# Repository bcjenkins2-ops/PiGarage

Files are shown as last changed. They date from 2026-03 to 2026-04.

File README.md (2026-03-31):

# PiGarage

Open-source Raspberry Pi power management and audio HAT for automotive head-unit use.

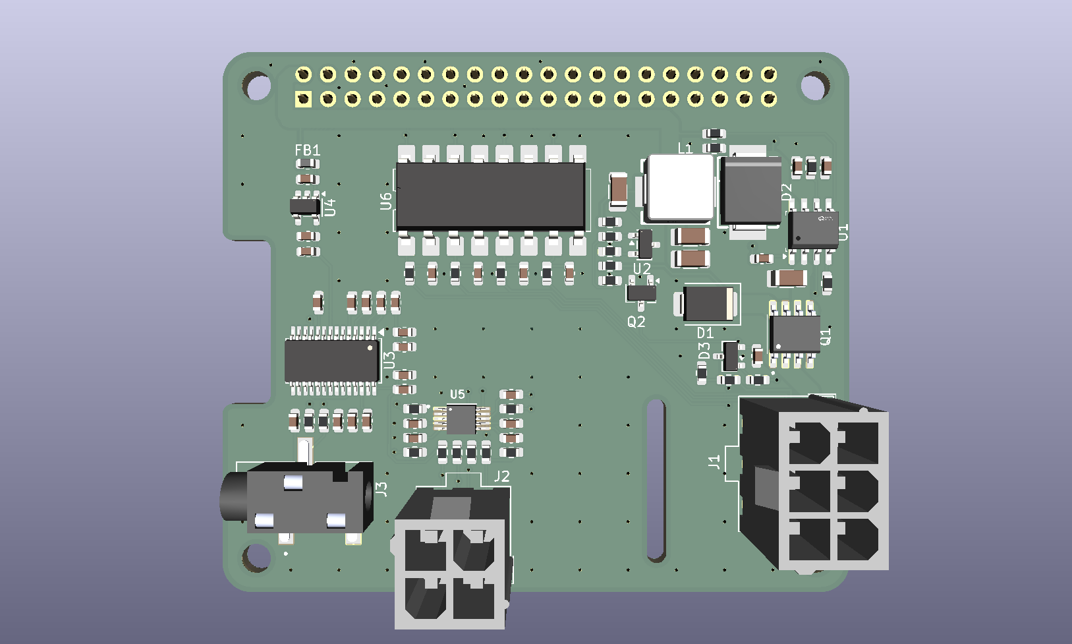
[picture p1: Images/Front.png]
PiGarage Board


## Features

- **5V 5A Buck Converter** (TPS54560BQDDARQ1) — 7-16V input, Pi 5 compatible
- **I2S DAC** (PCM5122PWR) — 112dB SNR, noise-free audio output to external amplifier
- **ADC** (ADS1115) — 16-bit, for steering wheel resistor ladder controls
- **4-Channel Optoisolated 12V Sensing** — ACC, REV, ILL, AUX via LTV-847S
- **Safe Shutdown** — ACC-triggered power latch with GPIO hold (BCM25), crank ride-through
- **Battery Protection** — UVLO hard cutoff at 12.08V via TL431A comparator
- **Compatible** — Raspberry Pi 3, 4, and 5

## Board

| Parameter | Value |
|---|---|
| Input Voltage | 7-16V (automotive 12V) |
| Output Voltage | 5.0V |
| Output Current | 5A continuous |
| DAC SNR | 112dB |
| DAC Interface | I2S |
| ADC Resolution | 16-bit, 4-channel |
| Sense Inputs | 4ch optoisolated |
| Board Format | Raspberry Pi HAT (65mm x 56.5mm) |

## Directory Layout

```
PiGarage/
├── Hardware/           KiCad 10 schematic, PCB, and custom libraries
├── Production/         Gerbers, drill files, pick-and-place
├── BOM/                Bill of Materials and design notes
├── Images/             Board renders and schematic exports
├── Software/           Power latch daemon and systemd service
└── Docs/               Ordering and assembly guide
```

## Getting Started

See [Docs/ordering-guide.md](Docs/ordering-guide.md) for full instructions on ordering from JLCPCB and assembling the board.

## License

Hardware: [CERN-OHL-S-2.0](https://ohwr.org/cern_ohl_s_v2.txt) — Software: MIT

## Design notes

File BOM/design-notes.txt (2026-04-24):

# PiGarage — Bill of Materials (BOM) Reference
**Last updated: 2026-04-25 (rev 15 — 0402→0603 passives for JLCPCB assembly)**

All SMT parts assembled by JLCPCB PCBA unless noted.

**Hand-solder (4 through-hole parts):**
- 40-pin GPIO header 2×20
- Molex Mini-Fit Jr 6-pin car harness header
- Molex Mini-Fit Jr 4-pin ADC header
- PJ-320B 3.5mm TRS audio jack

**Wire-side parts (DigiKey — see Section 7 for full shopping list):**
- Discrete cable assemblies: cut in half for colour-coded pigtails

---

## SECTION 1 — POWER INPUT & PROTECTION

**7.5A ATO/ATC fuse is installed in the car harness before J1, not on the PCB. Document only — no schematic symbol.**

### 2. SMBJ18CA/TR13 — TVS Diode
- **JLCPCB:** C78413
- **Package:** SMB (DO-214AA)
- **Mfr:** Brightking
- **Rating:** 600W, 18V standoff, BIDIRECTIONAL
- **Stock:** ~62,000
- **Notes:** BIDIRECTIONAL essential 

### 2b. B560C-13-F — Catch (Freewheeling) Schottky Diode
- **JLCPCB:** C85100
- **Package:** SMC (DO-214AB)
- **Mfr:** Diodes Incorporated
- **Specs:** 60V, 5A, Vf 0.7V typ @ 5A, -55 to +125°C
- **Notes:** REQUIRED — TPS54560B is asynchronous (high-side MOSFET only). External catch diode provides freewheeling path for inductor current when high-side FET turns off. Without this diode the converter will not function. Connect anode to GND, cathode to SW pin. Place as close to buck IC as possible with short, wide traces. SMC package chosen over SMA for better thermal performance at sustained 5A (θJA ~45°C/W vs ~90°C/W). Diode dominates thermal budget (~2W at full load) — ensure adequate copper pour under thermal pad.

---

## SECTION 2 — BUCK CONVERTER (12V → 5V @ 5A)

**Compensation designed with TI WEBENCH (7-16V in, 5V/5A out, ~1.1MHz fsw):**
```
Rcomp = 23.7kΩ, Ccomp = 1.8nF, Ccomp2 = 8.2pF
Rfbt = 60.4kΩ, Rfbb = 11.5kΩ → Vout = 0.8 × (1 + 60.4k/11.5k) = 5.0V
Rt = 80.6kΩ → fsw ≈ 1.1MHz
L1 = 2.2µH (molded/shielded)
```

### 3. TPS54560BQDDARQ1 — Buck Converter IC
- **JLCPCB:** C2072188
- **Package:** SOP-8-EP
- **Mfr:** Texas Instruments
- **Specs:** 4.5-60V in, 5A out, AEC-Q100, 500kHz
- **Stock:** ~1,271

### 4. cjiang FXL0630-2R2-M — Inductor 2.2µH
- **JLCPCB:** C167218 (Extended)
- **Package:** SMD 7×6.6mm molded (shielded)
- **Specs:** 2.2µH, Isat 10A, Irms 9.5A, DCR 15mΩ, ±20%
- **Notes:** WEBENCH recommended 2.2µH for 7-16V input at ~1.1MHz fsw. Molded construction reduces EMI — important with DAC on same board. 10A Isat exceeds TPS54560B 7.5A peak current limit with margin. 15mΩ DCR gives 0.375W loss at 5A (better than previous 26.5mΩ).

### 5. Samsung CL31A476MPHNNNE — 47µF Ceramic Output Capacitor (×2)
- **JLCPCB:** C96123 (Basic)
- **Package:** 1206
- **Specs:** 47µF, 10V, X5R, ±20%
- **Stock:** ~497,515
- **Qty:** 2 (in parallel on VOUT rail)
- **Notes:** WEBENCH design at 1.1MHz requires ≥22.7µF effective output capacitance (load transient). 2× 47µF at 10V gives ~70-76µF effective after DC bias derating at 5V. 10V rating chosen per TI reference design for good capacitance retention at 5V output.

### 6. Capacitor — 1µF X5R 0603 (HF bypass parallel with item 5)
- **JLCPCB:** C15849 (Basic)
- **Mfr:** Samsung CL10A105KB8NNNC
- **Specs:** 1µF, 50V, X5R, 0603

### 7. Resistor — 60.4kΩ (Rfbt, feedback divider top)
- **JLCPCB:** C23089 (Extended)
- **Specs:** 60.4kΩ, 1%, 0603
- **Notes:** Vout = 0.8 × (1 + 60.4k/11.5k) = 5.0V. WEBENCH value.

### 8. Resistor — 11.5kΩ (Rfbb, feedback divider bottom)
- **JLCPCB:** C2930057 (Extended)
- **Specs:** 11.5kΩ, 1%, 0603

### 9. Resistor — 80.6kΩ (RT, switching frequency)
- **JLCPCB:** C23249 (Extended)
- **Specs:** 80.6kΩ, 1%, 0603
- **Notes:** RT/CLK pin to GND → fsw ≈ 1.1MHz. WEBENCH value for 7-16V input.

### 10. Capacitor — 100nF X7R 0603 (BOOT pin)
- **JLCPCB:** C14663 (Basic)
- **Mfr:** YAGEO CC0603KRX7R9BB104
- **Specs:** 100nF, 50V, X7R, 0603
- **Notes:** BOOT cap sits between BOOT and SW pins per datasheet. Voltage across cap = ~5.4V (bootstrap charge), NOT 19.8V to GND. 50V rating provides 9.3× derating. All 100nF caps on the board now use C14663 (0603).

### 10b. Capacitor — 4.7µF 50V X7R 1206 (VIN input capacitor)
- **JLCPCB:** C29823 (Basic)
- **Mfr:** FH (Guangdong Fenghua) 1206B475K500NT
- **Specs:** 4.7µF, 50V, X7R, 1206
- **Stock:** ~620,000
- **Notes:** WEBENCH recommended 4.7µF 50V for input. Place directly next to U2 VIN pin. 50V rating provides 3× derating above TVS clamp voltage (16V). 1206 package needed for 50V rating at this capacitance.

### 11. Resistor — 23.7kΩ (R_comp)
- **JLCPCB:** C165751 (Extended)
- **Specs:** 23.7kΩ, 1%, 0603
- **Notes:** WEBENCH value for 7-16V, 5V/5A, ~1.1MHz.

### 12. Capacitor — 1.8nF C0G/NP0 0603 (C_comp)
- **JLCPCB:** C97878 (Extended)
- **Mfr:** Murata GRM1885C1H182JA01D
- **Specs:** 1.8nF, 50V, C0G/NP0, 0603
- **Notes:** WEBENCH value for 7-16V, 5V/5A, ~1.1MHz. MUST be C0G/NP0.

### 13. Capacitor — 8.2pF C0G/NP0 0603 (C_comp2)
- **JLCPCB:** C162249 (Extended)
- **Mfr:** Murata GRM1885C1H822JA01D
- **Specs:** 8.2pF, 50V, C0G/NP0, 0603
- **Notes:** WEBENCH value. HF pole capacitor.

---

## SECTION 3 — POWER MANAGEMENT LATCH

**Topology:** Diode-OR on EN pin. Two independent sources can hold EN HIGH:
- (A) ACC 12V via resistor divider → D1 → EN (V_EN = 1.76V)
- (B) BCM25 3.3V via 4.7kΩ series → D2 → EN

BAT54CLT1G (SOT-23 common-cathode dual Schottky):
- Anode 1 (pin 1) = D1 ← ACC divider output
- Anode 2 (pin 3) = D2 ← BCM25 via 4.7kΩ
- Cathode (pin 2) = EN node (shared)

**WHY TWO DIODES ARE REQUIRED:**
- D1 prevents ACC divider from pulling EN LOW when ACC turns off. Without D1: BCM25 fights (100k+22k) to GND at EN, V_EN drops to 0.58V.
- D2 prevents ACC from back-feeding BCM25 when Pi drives it LOW. Without D2: ACC holds BCM25 at 2.16V, shutdown is impossible.

**BOOT BEHAVIOUR (BCM25 high-Z, Pi booting):**
Only ACC holds EN via D1 at 1.76V > 1.2V threshold. Pi boots normally. If ACC drops during boot: EN decays in τ≈180ms, Pi loses power. This is correct behaviour — user turned off ignition. NO Pi 3.3V pull-up is used. Reason: Pi 3.3V pull-up creates a path that prevents BCM25 LOW from ever cutting power (circular dependency).

**SHUTDOWN BEHAVIOUR:**
BCM25 driven LOW → D2 reverse biases → EN decays through forward-biased D1 via divider resistors (22kΩ ∥ 100kΩ = 18kΩ) to GND. τ = 10µF × 18kΩ = 180ms. Buck disables in ~170ms. Note: this only works when ACC is off (D1 anode at 0V, D1 forward biases). If ACC is still active, D1 anode sits at 2.16V and holds EN above the 1.1V disable threshold — software shutdown while ACC on is not possible (see Known Limitations).

**UVLO OVERRIDE (see Section 4):**
NPN collector pulls EN to ~0.1V when battery < 12V. 4.7kΩ series R on BCM25 limits GPIO current to 0.64mA when UVLO fires. UVLO reliably cuts power when BCM25 is high-Z (Pi halted or crashed). At 4.7kΩ: I_BCM25 = 0.574mA << NPN I_C_max 2.15mA → NPN wins.

### 14. BAT54CLT1G — Dual Schottky Common Cathode (D1 + D2)
- **JLCPCB:** C916424 (Extended)
- **Package:** SOT-23
- **Specs:** 30V, 200mA, Vf=1.0V@100mA, -55 to +125°C
- **Stock:** ~127,879
- **Notes:** Pin 1=D1 anode (ACC), pin 3=D2 anode (BCM25), pin 2=EN.

### 15. Resistor — 100kΩ (ACC divider top / EN pull-down)
- **JLCPCB:** C25803
- **Mfr:** UNI-ROYAL 0603WAF1003T5E
- **Specs:** 100kΩ, 1%, 0603 | Stock: ~14,800,000
- **Notes:** ACC 12V → 100k/22k divider → D1. V_divider = 2.16V at 12V. When ACC is off (0V), this resistor + 22kΩ form the EN discharge path through forward-biased D1 (effective R = 22k∥100k = 18kΩ). No dedicated EN-to-GND pull-down exists.

### 16. Resistor — 22kΩ (ACC divider bottom)
- **JLCPCB:** C31850
- **Mfr:** UNI-ROYAL 0603WAF2202T5E
- **Specs:** 22kΩ, 1%, 0603 | Stock: ~1,800,000
- **Notes:** Also used for UVLO TL431 divider bottom (item 23).

### 17. Resistor — 4.7kΩ (BCM25 series protection)
- **JLCPCB:** C23162
- **Mfr:** UNI-ROYAL 0603WAF4701T5E
- **Specs:** 4.7kΩ, 1%, 0603 | Stock: ~9,100,000
- **Notes:** Raised from 1kΩ to ensure UVLO NPN wins with thick margin if BCM25 sticks HIGH. At 1kΩ: NPN barely wins (1.7mA vs 2.15mA at V_EN=1.1V — thin margin). At 4.7kΩ: NPN wins easily (0.36mA vs 2.15mA — thick margin). ✓ GPIO current when UVLO fires: (3.3-0.3)/4.7k = 0.64mA (safer). EN rise time when BCM25 HIGH: τ = 4.7k × 10µF = 47ms (acceptable). C21190 (1kΩ) still used for R_k in UVLO section (item 24).

### 18. Capacitor — 10µF 0805 (EN hold-up / crank ride-through)
- **JLCPCB:** C15850
- **Mfr:** YAGEO CC0805KKX7R7BB106
- **Specs:** 10µF, 16V, X7R, 0805 | Stock: ~292,000
- **Notes:** Shutdown: τ = 10µF × 18kΩ (22k∥100k through D1) = 180ms. Crank ride-through: during boot (before BCM25 asserts), EN cap held by TPS54560B internal 4.6µA pullup — barely decays during 500ms crank dip. Once BCM25 active, BCM25 holds EN regardless of ACC dips. Also used ×4 for DAC decoupling (items 29, 34, 36, 40).

### 19. MMBT3904 — NPN Transistor (UVLO output stage)
- **JLCPCB:** C20526
- **Package:** SOT-23 | Stock: ~1,300,000
- **Notes:** Collector → EN node. Emitter → GND. Pulls EN to ~0.1V (< 1.1V disable threshold) when UVLO fires.

---

## SECTION 4 — LOW VOLTAGE HARD CUTOFF (UVLO)

Hardware 12V cutoff, no microcontroller required. Protects battery from deep discharge if Pi crashes with BCM25 high-Z.

**TL431 behaviour (open-loop comparator mode — no cathode-to-REF feedback):**
- V_BAT > 12.1V (good): TL431 conducts, V_cathode ≈ 2.0V typical (comparator VOL per TI SLVA987A; worst-case 2.5V)
- V_BAT < 12.1V (low): TL431 off, V_cathode → 5V via R_k

**NPN base divider translates this (R_b1=47kΩ, R_b2=10kΩ):**
- Battery GOOD (typical): V_base = 2.0 × 10/(47+10) = 0.351V < 0.7V → NPN OFF [margin: 349mV @ 25°C]
- Battery GOOD (worst-case V_cathode=2.5V): V_base = 0.439V [margin: 261mV @ 25°C]
- Battery BAD: V_base = 5.0 × 10/(47+10) = 0.877V > 0.7V → NPN ON

**Verified over temperature (-40 to +125°C, Vbe from 0.85V to 0.45V):**
- +125°C, battery good (typical): V_base = 0.351V vs Vbe=0.45V → NPN OFF (99mV margin)
- +125°C, battery good (worst-case): V_base = 0.439V vs Vbe=0.45V → NPN OFF (11mV margin)
- +125°C, battery bad: I_B = (5.0-0.45)/47k - 0.45/10k = 51.8µA → I_C = hFE × I_B = 50 × 51.8µA = 2.59mA >> 96µA (ACC source) → saturates

**NOTE:** At +125°C the worst-case NPN-off margin is 11mV (if V_cathode = 2.5V); typical is ~99mV (V_cathode ≈ 2.0V). This is an extreme case for a fan-cooled in-car install (typical 40-70°C where margins are 250–400mV). Adequate for v1; use comparator IC for v2.

**Threshold math:**
```
V_cutoff = 2.495 × (84.5k + 22k)/22k = 12.08V
TL431 minimum cathode current: I_k = (5-2.0)/1k = 3.0mA > 1mA minimum. ✓
  (worst-case at V_cathode=2.5V: I_k = 2.5mA > 1mA ✓)
```

**Blanking cap on TL431 REF pin:**
```
τ = (Ra||Rb) × C = 17.6kΩ × 47µF = 827ms
Engine crank voltage dips (<500ms) do not trigger UVLO. System rides through.
```

### 20. TL431AQDBZR — Adjustable Shunt Regulator
- **JLCPCB:** C105255
- **Package:** SOT-23-3
- **Mfr:** Texas Instruments
- **Specs:** AEC-Q100, -40 to +125°C
- **Stock:** ~5,492

### 21. Resistor — 84.5kΩ (TL431 divider top R_a)
- **JLCPCB:** C23118 (Extended)
- **Mfr:** UNI-ROYAL 0603WAF8452T5E
- **Specs:** 84.5kΩ, 1%, 0603 | Stock: ~53,000
- **Notes:** Sets 12.1V cutoff threshold.

### 22. Resistor — 22kΩ (TL431 divider bottom R_b)
- **JLCPCB:** C31850 (same as item 16)

### 23. Resistor — 1kΩ (R_k, TL431 cathode pull-up from 5V)
- **JLCPCB:** C21190
- **Notes:** 5V → R_k → TL431 cathode → GND (through TL431 when bat good).

### 24. Resistor — 47kΩ (R_b1, NPN base divider top)
- **JLCPCB:** C25819
- **Mfr:** UNI-ROYAL 0603WAF4702T5E
- **Specs:** 47kΩ, 1%, 0603 | Stock: ~5,100,000

### 25. Resistor — 10kΩ (R_b2, NPN base divider bottom)
- **JLCPCB:** C25804 (same as item 8)

### 26. Capacitor — 47µF 10V X5R 1206 (TL431 REF blanking cap)
- **JLCPCB:** C96123 (Basic)
- **Mfr:** Samsung CL31A476MPHNNNE
- **Specs:** 47µF, 10V, X5R, 1206
- **Notes:** τ = 17.6kΩ × 47µF = 827ms. Handles cold crank ~500ms with margin. Same part as output caps (items 5).

---

## SECTION 5 — AUDIO DAC

**Power domains:**
- AVDD (3.3V) ← AP2112K LDO (item 31), fed via ferrite (item 30) from 5V rail
- DVDD (3.3V) ← Pi 3.3V rail directly (Pi's own regulator)
- CPVDD (3.3V) ← Pi 3.3V rail directly (same source as DVDD)

**Ground:** All ground connections in the audio section use the shared GND net. AGND was merged into GND for v0.2 — the PCM5122 datasheet confirms shared ground is acceptable. Physical separation between buck converter and DAC sections on the PCB provides noise isolation.

**Control pin wiring (no BOM items — direct traces in schematic):**
- MODE1 (pin 17) → DGND — selects I2C control mode (MODE1=LOW, MODE2=HIGH)
- MODE2 (pin 18) → DVDD — selects I2C control mode
- SCK (pin 20) → DGND — required for 3-wire I2S (BCK PLL mode). Device auto-detects missing SCK after 16 LRCK periods and starts internal PLL from BCK. Floating SCK may prevent reliable PLL lock.
- GPIO3 (pin 15), GPIO4 (pin 14), GPIO5 (pin 13), GPIO6 (pin 19) → leave unconnected (internal pull-downs in I2C mode)

### 27. PCM5122PWR — Audio DAC
- **JLCPCB:** C962071
- **Package:** TSSOP-28 *** 28-pin, NOT 20-pin ***
- **Mfr:** Texas Instruments
- **Specs:** 112dB SNR, I2S, I2C. Supply: AVDD/CPVDD/DVDD all 3.3V (abs max 3.9V — do NOT connect any pin to 5V)
- **Stock:** ~107
- **GPIO:** BCM18 BCLK, BCM19 LRCLK, BCM21 DOUT→DIN (Pi's PCM_DOUT sends audio to PCM5122 DIN pin 22. BCM20 PCM_DIN not connected — DAC has no data output in I2C mode)
- **I2C addr:** 0x4D (ADR1=DVDD, ADR2=GND — matches HiFiBerry DAC+ pinout. See items 37/38)
- **Notes:** C9034 is a microcontroller — completely wrong part. Driver controls XSMT and format via I2C. HiFiBerry DAC+ overlay chosen for maximum ecosystem compatibility (Volumio, Moode, LibreELEC, etc.). No on-board oscillator — DAC runs in slave mode (Pi generates BCK/LRCK, PCM5122 PLL derives internal clocks from BCK).
- **config.txt overlay (choose ONE based on Pi model):**
  - Pi 4 and older: `dtoverlay=hifiberry-dacplus` (driver auto-detects slave mode)
  - Pi 5: `dtoverlay=hifiberry-dacplus-std` (Pi 5 cannot dynamically switch clock direction; slave must be set at load time. Alternatively: `dtoverlay=hifiberry-dacplus,slave`)

### 28. Capacitor — 100nF X7R 0603 (AVDD decoupling)
- **JLCPCB:** C14663

### 29. Capacitor — 10µF 0805 (AVDD bulk)
- **JLCPCB:** C15850 (same as item 18)

### 30. GZ1608D601TF — Ferrite Bead (AVDD supply isolation)
- **JLCPCB:** C1002
- **Package:** 0603 | Mfr: Sunlord
- **Specs:** 600Ω @ 100MHz, 200mA, 450mΩ DCR | Stock: ~698,000

### 31. AP2112K-3.3TRG1 — Ultra-Low-Noise LDO (DAC AVDD)
- **JLCPCB:** C51118
- **Package:** SOT-25-5 | Mfr: Diodes Incorporated
- **Specs:** 3.3V, 600mA, 50µVrms noise, 65dB PSRR@1kHz | Stock: ~196,000
- **Notes:** EN (pin 3) tied to VIN (pin 1) for always-on operation. EN has 3MΩ internal pull-down — will be OFF if left floating.

### 31b. Capacitor — 1µF X7R 0402 (AP2112K LDO input decoupling) *** NEW ITEM ***
- **JLCPCB:** C52923 (same as items 6, 42)
- **Specs:** 1µF, 10V, X7R, 0402
- **Notes:** Required per AP2112K datasheet (CIN ≥ 1µF). Place between ferrite bead output (item 30) and LDO VIN pin (item 31). Without this cap, ferrite HF attenuation is degraded and LDO line transient response suffers.

### 32. Capacitor — 100nF X7R 0603 (AVDD LDO output decoupling)
- **JLCPCB:** C14663

### 33. Capacitor — 100nF X7R 0603 (DVDD decoupling, Pi 3.3V rail)
- **JLCPCB:** C14663

### 34. Capacitor — 10µF 0805 (DVDD bulk)
- **JLCPCB:** C15850 (same as item 18)

### 35. Capacitor — 100nF X7R 0603 (CPVDD decoupling)
- **JLCPCB:** C14663
- **Notes:** CPVDD is DAC charge pump supply input. Sourced from Pi 3.3V rail (NOT 5V — abs max 3.9V).

### 36. Capacitor — 10µF 0805 (CPVDD bulk)
- **JLCPCB:** C15850 (same as item 18)

### 37. Resistor — 10kΩ to DVDD (PCM5122 ADR1 pin 24, I2C address bit 0) *** CHANGED from GND to DVDD ***
- **JLCPCB:** C25804 (same as item 8)
- **Notes:** MUST NOT float. ADR1=DVDD, ADR2=GND → address 0x4D (matches HiFiBerry DAC+ for maximum overlay/driver compatibility).

### 38. Resistor — 10kΩ to GND (PCM5122 ADR2 pin 16, I2C address bit 1)
- **JLCPCB:** C25804 (same as item 8)

### 39. XSMT (PCM5122 pin 25) — tied directly to 3.3VA
- **No component needed** — R14 removed.
- **Notes:** XSMT tied to 3.3VA keeps DAC always unmuted. PCM5122 has built-in clock halt detection that auto-mutes when I²S clocks stop. If audible pops occur on shutdown, update pigarage.service to stop the audio service and wait ~50ms before cutting power. This lets the DAC detect clock loss and mute before power is removed.

### 40. Capacitor — 10µF 0805 (VNEG pin 5 decoupling — negative charge pump rail)
- **JLCPCB:** C15850 (same as item 18)
- **Notes:** PCM5122 VNEG pin 5. Negative rail ~-3.3V from charge pump. Required for pump stability.

### 41. Capacitor — 100nF X7R 0603 (LDOO pin 26 decoupling)
- **JLCPCB:** C14663
- **Notes:** PCM5122 internal 1.8V LDO output pin. Must be decoupled to GND.

### 42. Capacitor — 1µF X7R 0402 (CAPM/CAPP flying capacitor)
- **JLCPCB:** C52923 (same as item 6)
- **Notes:** Charge pump flying cap. Connected BETWEEN CAPP (pin 2) and CAPM (pin 4) — NOT to GND. Both pins float if this is omitted. VCOM (pin 10): wire to GND directly, NO cap required. Default VREF mode needs no decoupling on VCOM.

### 43. Resistor — 470Ω 0402 1% (RC filter series R, ×2 one per channel)
- **JLCPCB:** C23179
- **Mfr:** UNI-ROYAL 0603WAF4700T5E
- **Specs:** 470Ω, 1%, 0603 | Stock: ~2,960,000
- **Notes:** All PCM5122 datasheet performance specs (112dB SNR, -93dB THD+N) are measured with 470Ω + 2.2nF. Provides better out-of-band noise attenuation (~10dB at 500kHz vs ~0dB with 100Ω).

### 44. Capacitor — 2.2nF C0G/NP0 0603 50V (RC filter shunt C, ×2 one per channel)
- **JLCPCB:** C77033 (Extended)
- **Mfr:** Murata GRM1885C1H222JA01D
- **Specs:** 2.2nF, 50V, C0G/NP0, 0603
- **Notes:** fc = 1/(2×π×470×2.2n) = 154kHz. MUST be C0G/NP0 — X7R is voltage-dependent and introduces measurable audio distortion. Fallback: two 1nF C0G 0402 (C113780) in parallel per channel (gives 2.0nF, fc = 170kHz).

### 45. PJ-320B — 3.5mm TRS Audio Jack
- **JLCPCB:** C22355831
- **Package:** SMD, 3-pin TRS | Mfr: SHOU HAN
- **KiCad FP:** PJ-320B:BOOMELE_PJ-320B
- **Notes:** Pin 1=Sleeve(GND), Pin 2=Tip(Left), Pin 3=Ring(Right). Only L/R/GND needed — no mic pin. Hand-soldered. Use 3.5mm→RCA adapter if RCA output needed.

---

## SECTION 6 — GPIO SENSE INPUTS (×4 channels)

### *** OPEN SOURCE / COMMUNITY BUILD (canonical) ***

All four channels are identical sense inputs. BCM24 (AUX) is a spare input — use for any 12V car signal or leave unpopulated.

**Optoisolator circuit per channel (all four identical):**
```
Car 12V → 10kΩ → Anode (pin 1) → Cathode (pin 2) → Car GND
Pi internal pull-up (~50kΩ) → Collector (pin 4) → GPIO
Emitter (pin 3) → Pi GND
```

**Logic (ALL FOUR channels, same polarity):**
- Car signal 12V: LED on → transistor on → GPIO LOW (active)
- Car signal 0V: LED off → transistor off → GPIO HIGH (inactive)
- Handle any inversion in software. No hardware difference between channels.

```
LED current:   (12 - 1.2V) / 10kΩ = 1.08mA (adequate for FOD817BSD CTR rank B, 130% min)
GPIO current:  3.3V / 50kΩ = 66µA — transistor saturates, GPIO = ~0.1V
```

**GPIO assignments:**
- BCM17 — ACC (ignition sense)
- BCM22 — REV (reverse gear)
- BCM27 — ILL (illumination / headlights)
- BCM24 — AUX (spare input, user-defined)

### 46. LTV-847S — Quad Optoisolator (4 channels in one package)
- **JLCPCB:** C3294670 (Extended)
- **Package:** SMD-16P (2.54mm pitch) | Mfr: Lite-On
- **Specs:** 5kV isolation, 50mA, 35V Vceo, CTR 50-600%
- **Notes:** Replaces 4× individual LTV-817S. Same electrical specs per channel, smaller board footprint, single placement.

### 47. Resistor — 10kΩ ×4 (car-side LED current limit, all channels)
- **JLCPCB:** C25804 (same as item 8)
- **Notes:** Changed from 1kΩ. LED current = (12-1.2)/10k = 1.08mA. Adequate for FOD817.

### 48. Capacitor — 100nF ×4 (car-side debounce filter, in parallel with LED)
- **JLCPCB:** C14663
- **Notes:** RC filter: τ = 10kΩ × 100nF = 1ms. Filters noise/spikes on car signal. Place across opto LED pins (pin 1 to pin 2).

### *** NO external pull-up resistors on GPIO side ***
Pi internal pull-ups used instead (~50kΩ, enabled in software). Collector connects directly to GPIO net label. Emitter to GND.
```
GPIO.setup(pin, GPIO.IN, pull_up_down=GPIO.PUD_UP)
```
This is handled automatically by the PiGarage-monitor daemon on boot.

---

## SECTION 6b — ANALOG-TO-DIGITAL CONVERTER (ADS1115)

On-board 16-bit ADC for steering wheel button resistor ladder and general-purpose analog inputs. Powered from Pi 3.3V rail (150µA typical). Shared I2C bus with PCM5122 DAC — no additional GPIO pins used.

I2C address: 0x48 (ADDR to GND). No conflict with PCM5122 at 0x4D.

All four analog inputs (A0–A3) routed to the 4-pin Molex connector (item 51). Power and GND come from the board — no power pins on the connector. AIN0 and AIN1 each have a 4.7kΩ pull-up to 3.3V for resistor ladder excitation. AIN2/AIN3 have no pull-ups by default — users can populate if needed for additional resistor ladder channels. All inputs have 10kΩ series protection resistors.

### 52. ADS1115IRUGR — 16-bit ADC
- **JLCPCB:** C2651328
- **Package:** QFN-10 (2mm × 1.5mm)
- **Mfr:** Texas Instruments
- **Specs:** 16-bit, 860 SPS, 4-channel MUX, PGA ±0.256V to ±6.144V, I2C, 2V–5.5V supply
- **Notes:** Shared I2C bus with PCM5122 (BCM2 SDA, BCM3 SCL). Address 0x48 (ADDR to GND). ALRT pin (pin 2) left unconnected — internal pull-up present. Pi on-board 1.8kΩ I2C pull-ups adequate for combined bus. Linux driver: `ads1015` IIO driver or Adafruit_ADS1x15 Python library.

### 53. Capacitor — 100nF X7R 0603 (ADS1115 VDD decoupling)
- **JLCPCB:** C14663 (same as items 28, 32, 33, 35, 41, 48)
- **Notes:** Place directly at ADS1115 VDD pin 8.

### 54. Resistor — 10kΩ (ADS1115 ADDR to GND)
- **JLCPCB:** C25804 (same as items 8, 25, 37, 38, 39, 47)
- **Notes:** Sets I2C address to 0x48. Change destination for alternate addresses: VDD→0x49, SDA→0x4A, SCL→0x4B.

### 55. Resistor — 4.7kΩ ×2 (AIN0 + AIN1 pull-ups to 3.3V, resistor ladder excitation) *** UPDATED ×1→×2 ***
- **JLCPCB:** C23162 (same as item 17)
- **Notes:** Excitation for resistor ladder inputs on AIN0 and AIN1. No button pressed = input reads 3.3V. Button pressed = voltage divider with ladder resistance gives unique voltage per button. Value gives good spread across typical steering wheel ladder values (330Ω–3.3kΩ). AIN2/AIN3 have no pull-ups by default — populate additional 4.7kΩ if needed for more resistor ladder channels.

### 56. Resistor — 10kΩ ×4 (A0–A3 series input protection)
- **JLCPCB:** C25804 (same as item 54)
- **Notes:** One per channel. Limits input current if analog input accidentally exposed to 12V: (12 − 3.6) / 10kΩ = 0.84mA, well below 10mA abs max. Negligible voltage error due to >10MΩ ADC input impedance.

---

## SECTION 7 — CONNECTORS & MECHANICAL

### 49. 40-Pin GPIO Header (2×20)
- **Notes:** Hand-solder. Standard RPi HAT through-hole connector.

### 50. Car Harness Connector — Molex Mini-Fit Jr 6-pin (2×3)
- **PCB header:** [0455580003](https://www.digikey.com/en/products/detail/molex/0455580003/3311349) (vertical, dual row, 4.2mm pitch, black LCP, glow-wire)
- **Wire-side cable:** [0451350603](https://www.digikey.com/en/products/detail/molex/0451350603/6822677) — 6-circuit discrete cable, 300mm, colour-coded wires, housing pre-loaded. Cut in half → two pigtail harnesses.
- **KiCad FP:** Connector_Molex:Molex_Mini-Fit_Jr_5566-06A_2x03_P4.20mm_Vertical
- **Notes:** Mini-Fit Jr (4.2mm pitch), the standard ATX power connector. 13A per pin, -40 to +105°C. 2×3 dual row is compact and sturdy on the PCB (16.9mm wide). Hand-soldered.
- **Pinout:** Pin 1: BAT+ / Pin 2: GND / Pin 3: ACC / Pin 4: ILL / Pin 5: REV / Pin 6: AUX

### 51. ADC Analog Input Connector — Molex Mini-Fit Jr 4-pin (2×2)
- **PCB header:** Molex 0462071004 (vertical, dual row, 4.2mm pitch, black LCP, glow-wire)
- **Wire-side cable:** [0451350403](https://www.digikey.com/en/products/detail/molex/0451350403/6822667) — 4-circuit discrete cable, 300mm, colour-coded wires, housing pre-loaded. Cut in half → two pigtail harnesses.
- **KiCad FP:** Connector_Molex:Molex_Mini-Fit_Jr_5566-04A_2x02_P4.20mm_Vertical
- **Pinout:** Pin 1: A0 / Pin 2: A1 / Pin 3: A2 / Pin 4: A3
- **Notes:** All four ADS1115 analog inputs routed to connector. Power (3.3V) and GND for the ADC come from the board — no power pins needed. Steering wheel users connect A0 only. Same Mini-Fit Jr family as car harness. Hand-soldered.

### Molex Mini-Fit Jr — DigiKey Shopping List

| Qty | Part | DigiKey Link | Description | ~Price |
|-----|---|---|---|---|
| 2 | 0455580003 | [link](https://www.digikey.com/en/products/detail/molex/0455580003/3311349) | 6-pin PCB header, black LCP | $2.50 ea |
| 2 | 0462071004 | search DigiKey | 4-pin PCB header, black LCP | $2.00 ea |
| 1 | 0451350603 | [link](https://www.digikey.com/en/products/detail/molex/0451350603/6822677) | 6-ckt cable 300mm (cut in half → 2 pigtails) | ~$5 |
| 1 | 0451350403 | [link](https://www.digikey.com/en/products/detail/molex/0451350403/6822667) | 4-ckt cable 300mm (cut in half → 2 pigtails) | ~$4 |

Total: ~$16 for two complete connector sets with spares. One DigiKey order, no special tools.

### J3 — PJ-320B 3.5mm TRS Audio Jack
- **JLCPCB:** C22355831 — PJ-320B, SMD 3-pin TRS
- **Notes:** Hand-solder onto board. Standard 3.5mm jack — use any TRS cable or 3.5mm→RCA adapter for amplifier connection.

---

## GPIO ALLOCATION (10 of 28 used, 18 free)

| BCM | Function |
|-----|---|
| 2 | I2C SDA (PCM5122 DAC + steering wheel controller) |
| 3 | I2C SCL (PCM5122 DAC + steering wheel controller) |
| 17 | ACC sense |
| 18 | I2S BCLK |
| 19 | I2S LRCLK |
| 20 | FREE (Pi PCM_DIN — not used, DAC has no data output) |
| 21 | I2S DOUT (Pi transmits audio to PCM5122 DIN pin 22) |
| 22 | REV sense |
| 24 | AUX (spare, user-defined) |
| 25 | Power latch (HIGH = run, LOW = cut power) |
| 27 | ILL sense |

---

## KNOWN LIMITATIONS (v1 — flag for v2)

1. **UVLO NPN-OFF margin at +125°C: 11mV worst-case, ~99mV typical.** TL431 in comparator mode has VOL ≈ 2.0V (typical) giving 99mV margin, or 2.5V (worst-case) giving 11mV. Fan-cooled install typical temp 40-70°C — margin 250-400mV there. Fix for v2: use LMV331 or similar comparator with built-in reference, or add 470kΩ hysteresis resistor from cathode to divider junction.

2. **Pi loses power if ignition turned off during the 20s boot window.** Normal use case (ignition on while Pi boots) unaffected. Not worth fixing: if user turns off ignition, expected behaviour is power loss.

3. **UVLO cycling at battery cutoff.** When battery < 12.1V with ACC active, system cycles at ~8Hz (EN charge ~120ms + soft-start ~2ms per cycle). UVLO is powered from the 5V rail it disables, creating an inherent restart loop. Cycling is self-protective — prevents Pi from running and draining a dying battery. Battery drain during cycling is negligible (~2.5µA average). Verify on prototype. Fix for v2: add 470kΩ hysteresis resistor from TL431 cathode to Ra/Rb divider junction (~0.5V hysteresis band).

4. **AP2112K PSRR at 500kHz is ~30–40dB, not 65dB.** The 65dB datasheet figure is at 1kHz only. Combined rejection is adequate (~70–90dB total). If noise is audible on prototype, upgrade AVDD LDO to TPS7A47 or LP5907.

5. **Star ground layout is critical for audio quality.** Component choices give ~95–100dB rejection at 500kHz and >65dB PSRR at audio frequencies. Actual SNR depends entirely on PCB layout: star ground point placement, physical separation of buck from DAC, and no shared copper between switching return currents and audio ground. Must be enforced in KiCad layout.

6. **AP2112K absolute maximum VIN is 6.0V (recommended operating max 5.5V).** Buck output is 4.984V, giving 0.5V margin to recommended max and 1.0V to absolute max. TPS54560B OVP at 109% (5.43V) should prevent excursions, but probe LDO input on prototype for transients above 5.5V. If seen, add small series resistor (1–10Ω) before LDO or upgrade to higher-VIN LDO.

7. **AP2112K is commercial-grade (-40 to +85°C), not AEC-Q100.** Adequate for fan-cooled dash/under-seat install (typical 40–70°C, 15–45°C margin). For v2 full automotive-grade: consider TPS7A20 (TI, AEC-Q100) or equivalent.

8. **Software shutdown while ACC (ignition) is active is not possible.** BCM25 LOW releases D2, but ACC divider continues holding EN above 1.1V threshold through D1. System stays powered until ignition is turned off. This is correct behaviour for a car head unit — power should not cut while driving. The UVLO (NPN) is the only override that works regardless of ACC state.

9. **Power-on delay ~120ms from ignition on to buck enable.** EN cap (10µF) charges through D1 + divider impedance (18kΩ), τ = 180ms. EN reaches 1.1V threshold in ~120ms. Plus 2ms buck soft-start = ~122ms total before 5V rail is up. Negligible vs Pi boot time (seconds).

10. **AGND and GND connected via net tie at single star point.** PCB layout must enforce separate copper pour islands for audio ground and power ground, bridged only at the star point near the GPIO header. Failure to maintain ground separation will couple buck switching noise into the audio output, degrading SNR below the ~100dB target.

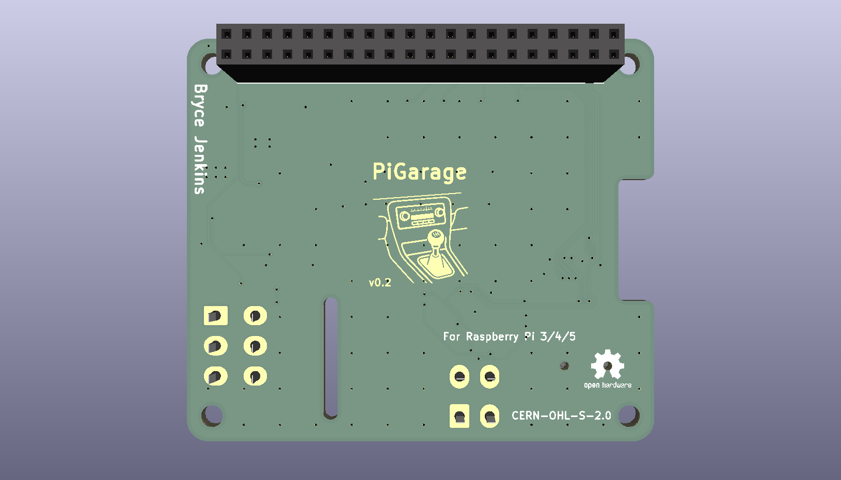
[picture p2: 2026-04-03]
Images/Back.png

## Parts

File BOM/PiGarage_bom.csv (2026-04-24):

Reference | Qty | Value | Footprint | MPN | Manufacturer | LCSC | LC_Stock | Chosen_Distributor | Datasheet | Validated | DNP | Notes
C1 | 1 | 4.7µF | 1206
C3 | 1 | 1.8nF | 0603
C4 | 1 | 8.2pF | 0603
C5,C6,C7 | 3 | 47µF | 1206
C9 | 1 | 1µF | 0603
C11,C8,C22,C12,C18,C20,C16 | 7 | 10µF | 0603
C15,C14 | 2 | 2.2µF | 0603
C21,C13,C17,C19 | 4 | 0.1µF | 0603 | CC0603KRX7R9BB104 | Yageo | C14663
C23,C24 | 2 | 2.2nF | 0603
C32,C2,C25,C31,C27,C33,C28,C10,C30,C26,C29 | 11 | 100nF | 0603
D1 | 1 | SMBJ18CA | SMB
D2 | 1 | B560C-13-F | SMC_L7.1-W6.2-LS8.1-RD
D3 | 1 | BAT54CLT1G | SOT-23
FB1 | 1 | 600R | 0603
J1 | 1 | Conn_02x03_Odd_Even | Molex_Mini-Fit_Jr_5566-06A_2x03_P4.20mm_Vertical
J2 | 1 | Conn_02x02_Counter_Clockwise | Molex_Mini-Fit_Jr_5566-04A_2x02_P4.20mm_Vertical
J3 | 1 | PJ-320B | BOOMELE_PJ-320B | PJ-320B | Luoyang Dishang electronics
J4 | 1 | Conn_02x20_Odd_Even | PinSocket_2x20_P2.54mm_Vertical
L1 | 1 | 2.2µH | IND-SMD_L7.0-W6.6
Q1 | 1 | AO4407A | SOIC127P600X175-8N
Q2 | 1 | MMBT3904 | TSOT-23 |  |  |  |  |  | https://www.onsemi.com/pdf/datasheet/pzt3904-d.pdf
R1 | 1 | 23.7kΩ | 0603
R2 | 1 | 80.6kΩ | 0603
R3 | 1 | 60.4kΩ | 0603
R4 | 1 | 11.5kΩ | 0603
R5 | 1 | 84.5kΩ | 0603 | 0603WAF8452T5E | UNI-ROYAL(Uniroyal Elec) | C23118
R6,R12 | 2 | 22kΩ | 0603 | 0603WAF2202T5E | UNI-ROYAL(Uniroyal Elec) | C31850
R7 | 1 | 1kΩ | 0603 | 0603WAF1001T5E | UNI-ROYAL(Uniroyal Elec) | C21190
R8 | 1 | 47kΩ | 0603 | 0603WAF4702T5E | UNI-ROYAL(Uniroyal Elec) | C25819
R10 | 1 | 100kΩ | 0603 | 0603WAF1003T5E | UNI-ROYAL(Uniroyal Elec) | C25803
R13,R14 | 2 | 470Ω | 0603 | 0603WAF4700T5E | UNI-ROYAL(Uniroyal Elec) | C23179
R18,R15,R16,R23,R9,R17,R26,R24,R25 | 9 | 10kΩ | 0603 | 0603WAF1002T5E | UNI-ROYAL(Uniroyal Elec) | C25804
R20,R19,R22,R11,R21 | 5 | 4.7kΩ | 0603 | 0603WAF4701T5E | UNI-ROYAL(Uniroyal Elec) | C23162
U1 | 1 | TPS54560BQDDARQ1 | Texas_R-PDSO-G8_EP2.95x4.9mm_Mask2.4x3.1mm_ThermalVias |  |  |  |  |  | https://www.ti.com/lit/ds/symlink/tps54560b.pdf
U2 | 1 | TL431DBZ | SOT-23 |  |  |  |  |  | http://www.ti.com/lit/ds/symlink/tl431.pdf
U3 | 1 | PCM5122PWR | TSSOP-28_4.4x9.7mm_P0.65mm
U4 | 1 | AP2112K-3.3 | SOT-23-5 |  |  |  |  |  | https://www.diodes.com/assets/Datasheets/AP2112.pdf
U5 | 1 | ADS1115IDGSR | SOP50P490X110-10N
U6 | 1 | LTV-847S | SMDIP-16_W9.53mm |  |  |  |  |  | http://www.us.liteon.com/downloads/LTV-817-827-847.PDF

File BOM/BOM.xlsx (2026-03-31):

Designator | Footprint | Quantity | Value | LCSC
C1 | C_1206_3216Metric | 1 | 4.7µF | C29823
C7,C10,C12,C16 | C_0805_2012Metric | 4 | 10ÂµF | C15850
C2 | C_0603_1608Metric | 1 | 100nF | C14663
C9,C11,C13,C20,C21,C22,C25 | C_0603_1608Metric | 7 | 100nF | C14663
C3,C17 | C_0603_1608Metric | 2 | 1ÂµF | C15849
C4,C26 | C_1206_3216Metric | 2 | 47µF | C96123
C5 | C_0603_1608Metric | 1 | 1.8nF | C97878
C6 | C_0603_1608Metric | 1 | 8.2pF | C162249
C18,C19 | C_0603_1608Metric | 2 | 10µF | C19702
D1 | SMB_L4.6-W3.6-LS5.3-BI | 1 | SMBJ18CA | C78413
D3 | SOT-23 | 1 | BAT54CLT1G | C916424
D2 | D_SMC | 1 | B560C-13-F | C85100
FB1 | L_0603_1608Metric | 1 | 600R | C1002
J3 | BOOMELE_PJ-320B | 1 | PJ-320B | C22355831
L1 | IND-SMD_L7.0-W6.6 | 1 | 2.2µH | C167218
Q1 | SOIC127P600X175-8N | 1 | AO4407A | C2841482
R1 | R_0603_1608Metric | 1 | 23.7kΩ | C165751
R2 | R_0603_1608Metric | 1 | 80.6kΩ | C23249
R5,R7,R13,R14,R17,R18,R19,R20,R22,R23,R24,R25,R26 | R_0603_1608Metric | 13 | 10kÎ© | C25744
R4 | R_0603_1608Metric | 1 | 11.5kΩ | C2930057
R6,R10 | R_0603_1608Metric | 2 | 22kÎ© | C25768
R8 | R_0603_1608Metric | 1 | 100kÎ© | C25741
R9 | R_0603_1608Metric | 1 | 84.5kÎ© | C26988
R11 | R_0603_1608Metric | 1 | 1kÎ© | C11702
R12 | R_0603_1608Metric | 1 | 47kÎ© | C25792
R15,R16 | R_0603_1608Metric | 2 | 470Î© | C25117
R21,R27,R28 | R_0603_1608Metric | 3 | 4.7kÎ© | C25900
U1 | SOP65P640X120-28N | 1 | PCM5122PWR | C962071
U2 | Texas_R-PDSO-G8_EP2.95x4.9mm_Mask2.4x3.1mm_ThermalVias | 1 | TPS54560BQDDARQ1 | C2072188
U3 | SOT-23 | 1 | TL431DBZ | C105255
U4 | SOT-23-5 | 1 | AP2112K-3.3 | C51118
U6 | SOIC254P1016X460-16N | 1 | LTV-847S | C3294670
U5 | TSSOP-10_3x3mm_P0.5mm | 1 | ADS1115IDGSR | C37593
R3 | R_0603_1608Metric | 1 | 60.4kΩ | C23089
C8 | C_0603_1608Metric | 1 | 10µF | C19702
Q2 | SOT-23 | 1 | MMBT3904 | C20526
C14,C15 | C_0603_1608Metric | 2 | 2.2µF | C23630
C23,C24 | C_0603_1608Metric | 2 | 2.2nF | C77033

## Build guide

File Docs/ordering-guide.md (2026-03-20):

# PiGarage Ordering & Assembly Guide

## 1. Prepare Production Files

Compress all files in the `Production/` folder into a `.zip` or `.rar`, **excluding** the position file (`PiGarage-all-pos.xlsx`). The zip should contain only Gerber and drill files.

## 2. Order PCBs with Assembly

1. Go to [JLCPCB](https://cart.jlcpcb.com/quote) and upload your compressed Gerber file.
2. The default settings should be fine. The main ones to confirm:
   - **Layers:** 2
   - **Thickness:** 1.6mm
   - **Surface Finish:** HASL (lead-free)
   - **Copper Weight:** 1oz
3. Scroll down and select **PCB Assembly**.
4. Set **PCBA Qty** to **2** (this is the minimum). Feel free to share the spare with someone else wanting to use a Pi as their head unit!

## 3. Upload BOM and CPL

- **BOM:** Upload `BOM/BOM.xlsx`
- **CPL (Component Placement List):** Upload `Production/PiGarage-all-pos.xlsx`

## 4. Check Component Orientation

In the **Component Placements** preview, you will need to ensure the components are oriented correctly. Line up each component's dot/pin-1 marker with the corresponding dot on the board. Rotate any that don't match.

## 5. Hand-Solder Remaining Parts

Not all components are available through JLCPCB assembly. Purchase the remaining parts from DigiKey (or your preferred distributor) and hand-solder them:

- **J1** — 40-pin Raspberry Pi GPIO header
- **J2** — Molex Mini-Fit Jr 4-pin power connector
- **J3** — PJ-320B 3.5mm audio jack

Refer to `BOM/PiGarage_BOM.txt` for the full parts list with part numbers.

## 6. Install Software

```bash
sudo mkdir -p /opt/pigarage
sudo cp Software/power_latch.py /opt/pigarage/power_latch.py
sudo cp Software/pigarage.service /etc/systemd/system/pigarage.service
sudo systemctl daemon-reload
sudo systemctl enable pigarage
sudo systemctl start pigarage
```

The service monitors ACC (BCM27) and holds the power latch (BCM25) high. When ACC drops for 3 seconds, the Pi shuts down safely and releases the latch.

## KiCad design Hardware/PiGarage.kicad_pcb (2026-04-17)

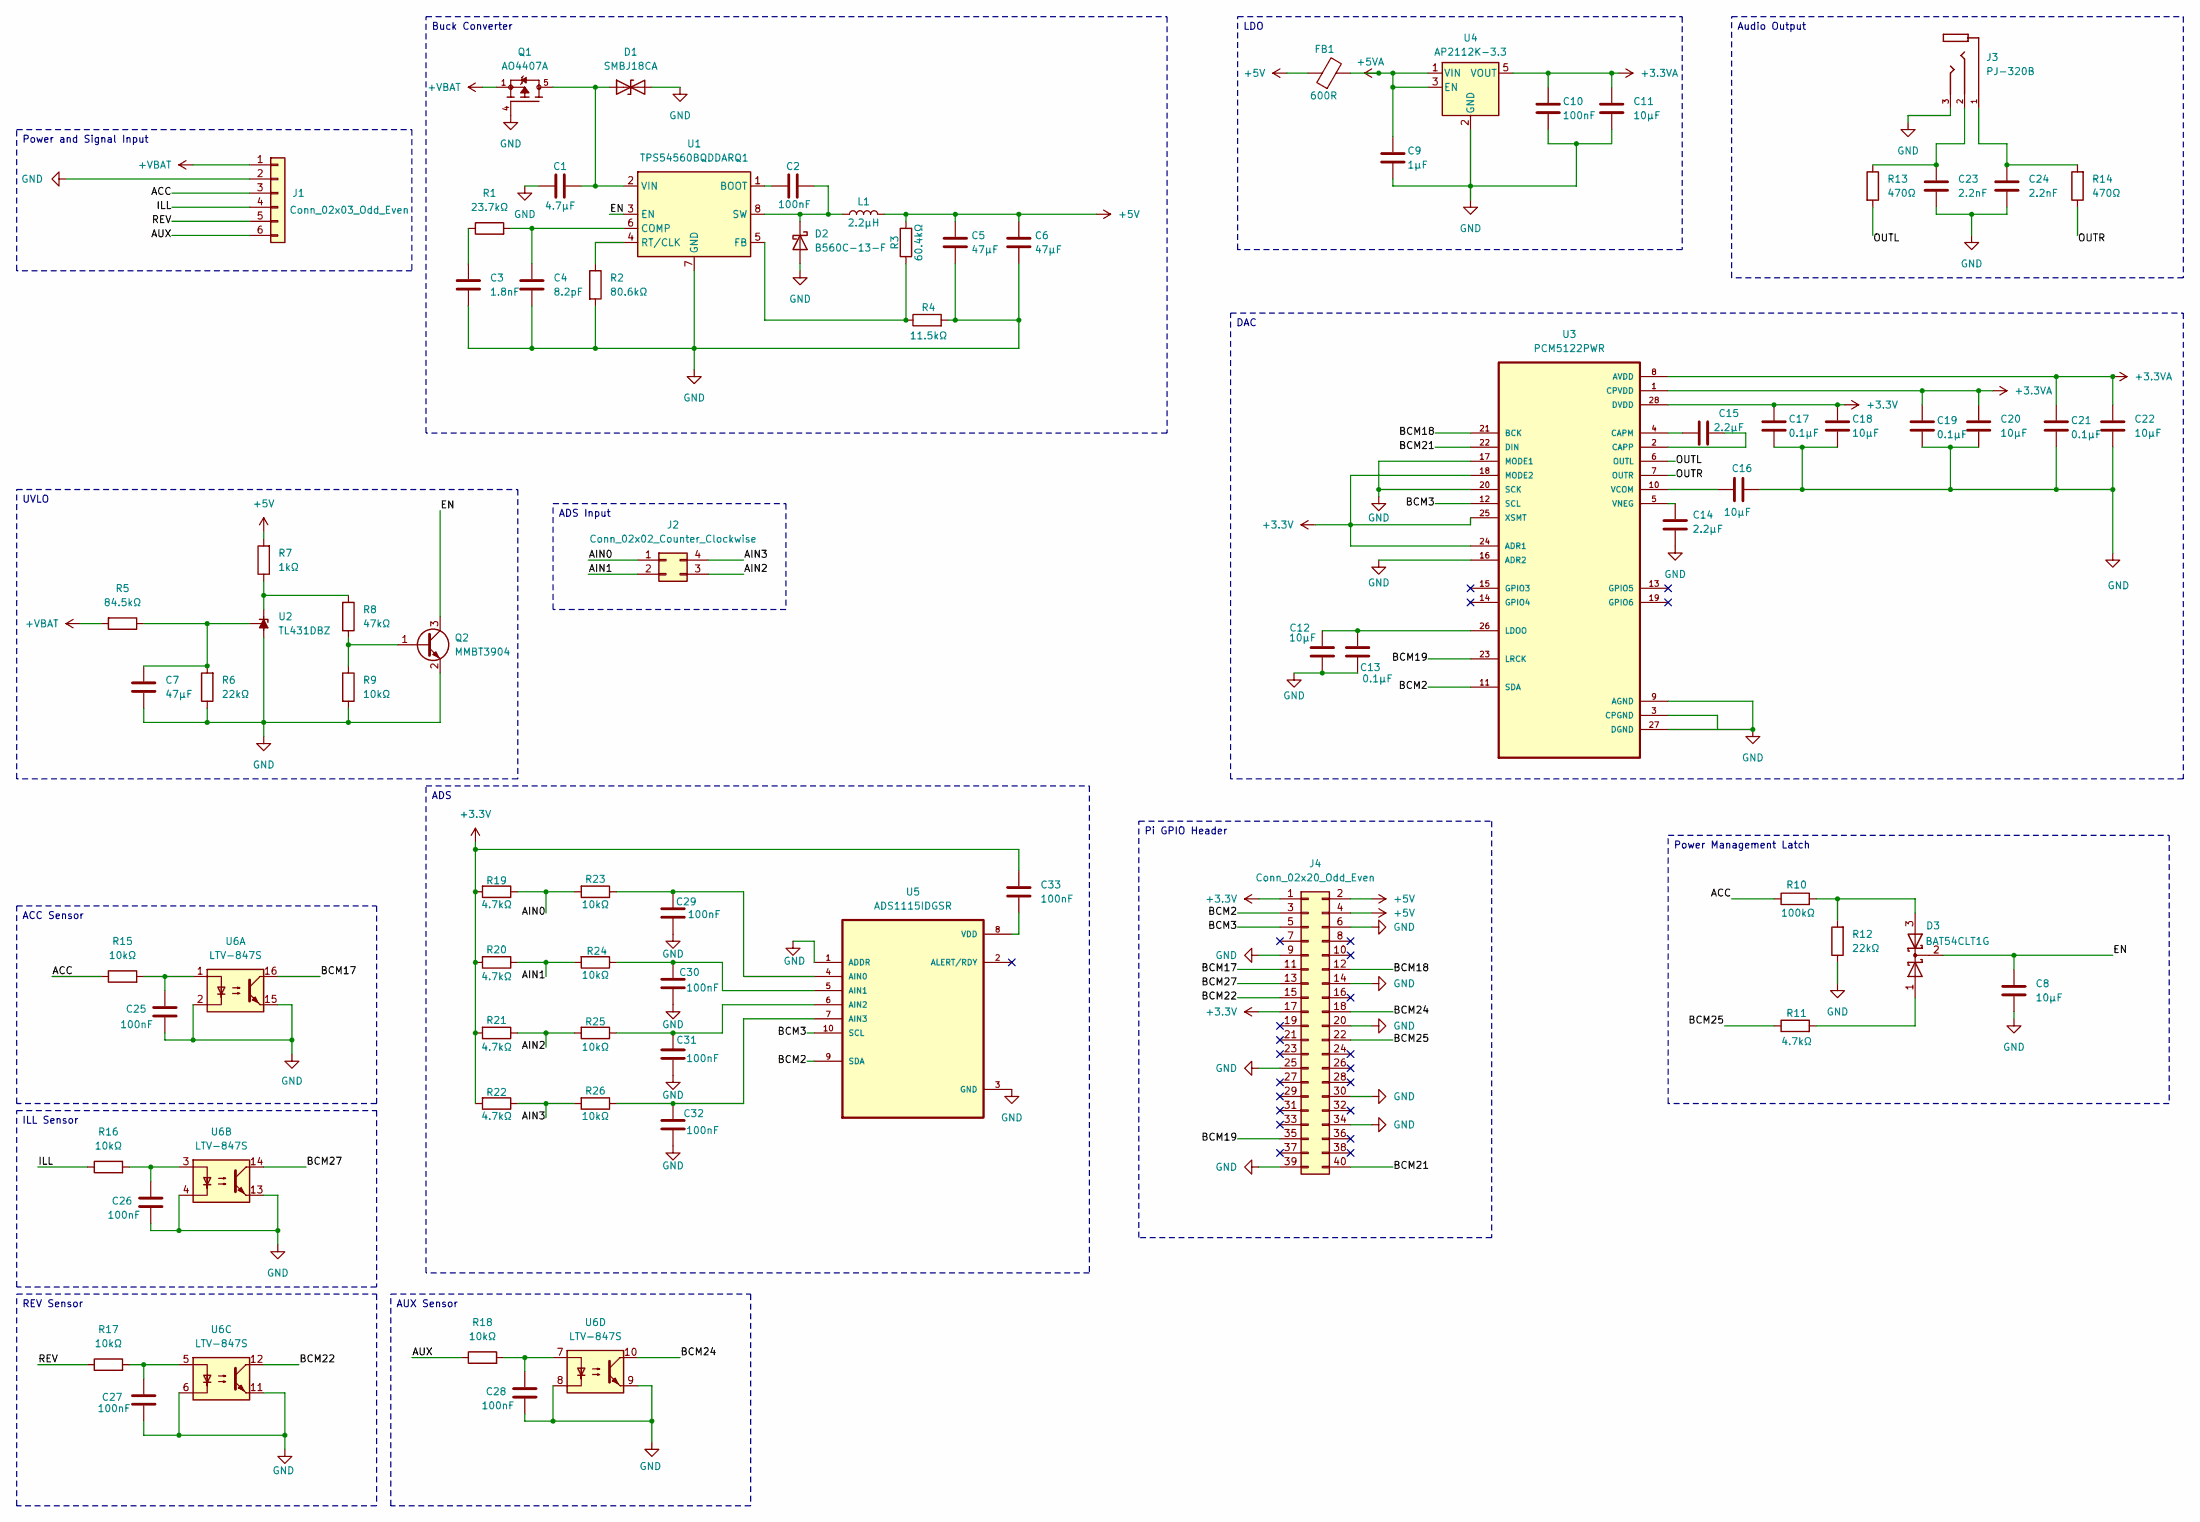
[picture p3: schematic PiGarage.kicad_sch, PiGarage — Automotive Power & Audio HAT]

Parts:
C1: 4.7µF; C_1206_3216Metric
C2, C10, C25, C26, C27, C28, C29, C30, C31, C32, C33: 100nF; C_0603_1608Metric
C3: 1.8nF; C_0603_1608Metric
C4: 8.2pF; C_0603_1608Metric
C5, C6, C7: 47µF; C_1206_3216Metric
C8, C11, C12, C16, C18, C20, C22: 10µF; C_0603_1608Metric
C9: 1µF; C_0603_1608Metric
C13, C17, C19, C21: 0.1µF; C_0603_1608Metric
C14, C15: 2.2µF; C_0603_1608Metric
C23, C24: 2.2nF; C_0603_1608Metric
D1: SMBJ18CA; D_SMB
D2: B560C-13-F; SMC_L7.1-W6.2-LS8.1-RD
D3: BAT54CLT1G; SOT-23
FB1: 600R; L_0603_1608Metric
J1: Conn_02x03_Odd_Even; Molex_Mini-Fit_Jr_5566-06A_2x03_P4.20mm_Vertical
J2: Conn_02x02_Counter_Clockwise; Molex_Mini-Fit_Jr_5566-04A_2x02_P4.20mm_Vertical
J3: PJ-320B; BOOMELE_PJ-320B; MPN PJ-320B
J4: Conn_02x20_Odd_Even; PinSocket_2x20_P2.54mm_Vertical
L1: 2.2µH; IND-SMD_L7.0-W6.6
Q1: AO4407A; SOIC127P600X175-8N; PARTREV I
Q2: MMBT3904; TSOT-23
R1: 23.7kΩ; R_0603_1608Metric
R2: 80.6kΩ; R_0603_1608Metric
R3: 60.4kΩ; R_0603_1608Metric
R4: 11.5kΩ; R_0603_1608Metric
R5: 84.5kΩ; R_0603_1608Metric
R6, R12: 22kΩ; R_0603_1608Metric
R7: 1kΩ; R_0603_1608Metric
R8: 47kΩ; R_0603_1608Metric
R9, R15, R16, R17, R18, R23, R24, R25, R26: 10kΩ; R_0603_1608Metric
R10: 100kΩ; R_0603_1608Metric
R11, R19, R20, R21, R22: 4.7kΩ; R_0603_1608Metric
R13, R14: 470Ω; R_0603_1608Metric
U1: TPS54560BQDDARQ1; Texas_R-PDSO-G8_EP2.95x4.9mm_Mask2.4x3.1mm_ThermalVias
U2: TL431DBZ; SOT-23
U3: PCM5122PWR; TSSOP-28_4.4x9.7mm_P0.65mm
U4: AP2112K-3.3; SOT-23-5
U5: ADS1115IDGSR; SOP50P490X110-10N
U6: LTV-847S; SMDIP-16_W9.53mm

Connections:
+3.3V: C17.1, C18.2, C33.1, J4.1, J4.17, R19.2, R20.2, R21.2, R22.2, U3.18 (MODE2), U3.24 (ADR1), U3.25 (XSMT), U3.28 (DVDD)
+3.3VA: C10.2, C11.2, C19.1, C20.2, C21.1, C22.2, U3.1 (CPVDD), U3.8 (AVDD), U4.5 (VOUT)
+5V: C5.1, C6.1, FB1.1, J4.2, J4.4, L1.2, R3.2, R7.2
+5VA: C9.1, FB1.2, U4.1 (VIN), U4.3 (EN)
/ACC: J1.3, R10.1, R15.1
/AIN0: J2.1, R19.1, R23.2
/AIN1: J2.2, R20.1, R24.2
/AIN2: J2.3, R21.1, R25.2
/AIN3: J2.4, R22.1, R26.2
/AUX: J1.6, R18.1
/BCM2: J4.3, U3.11 (SDA), U5.9 (SDA)
/BCM3: J4.5, U3.12 (SCL), U5.10 (SCL)
/BCM17: J4.11, U6.16
/BCM18: J4.12, U3.21 (BCK)
/BCM19: J4.35, U3.23 (LRCK)
/BCM21: J4.40, U3.22 (DIN)
/BCM22: J4.15, U6.12
/BCM24: J4.18, U6.10
/BCM25: J4.22, R11.1
/BCM27: J4.13, U6.14
/EN: C8.1, D3.2 (K), Q2.3 (C), U1.3 (EN)
/ILL: J1.4, R16.1
/OUTL: R13.2, U3.6 (OUTL)
/OUTR: R14.1, U3.7 (OUTR)
/REV: J1.5, R17.1
GND: C1.2, C3.2, C4.2, C5.2, C6.2, C7.1, C8.2, C9.2, C10.1, C11.1, C12.1, C13.1, C14.2, C16.1, C17.2, C18.1, C19.2, C20.1, C21.2, C22.1, C23.1, C24.2, C25.2, C26.2, C27.2, C28.2, C29.1, C30.2, C31.2, C32.2, D1.2 (A2), D2.2 (A), J1.2, J3.3, J4.6, J4.9, J4.14, J4.20, J4.25, J4.30, J4.34, J4.39, Q1.4, Q2.2 (E), R2.2, R4.2, R6.1, R9.2, R12.1, U1.7 (GND), U1.9 (GND), U2.3 (A), U3.9 (AGND), U3.16 (ADR2), U3.17 (MODE1), U3.20 (SCK), U3.27 (DGND), U4.2 (GND), U5.1 (ADDR), U5.3 (GND), U6.2, U6.4, U6.6, U6.8, U6.9, U6.11, U6.13, U6.15
unnamed: C3.1, R1.1
unnamed: C23.2, J3.2, R13.1
unnamed: C24.1, J3.1, R14.2
unnamed: C25.1, R15.2, U6.1
unnamed: C26.1, R16.2, U6.3
unnamed: C27.1, R17.2, U6.5
unnamed: C28.1, R18.2, U6.7
unnamed: C2.2, D2.1 (K), L1.1, U1.8 (SW)
unnamed: D3.1 (A), R11.2
unnamed: D3.3 (A), R10.2, R12.2
unnamed: Q2.1 (B), R8.2, R9.1
unnamed: C2.1, U1.1 (BOOT)
unnamed: C4.1, R1.2, U1.6 (COMP)
unnamed: R3.1, R4.1, U1.5 (FB)
unnamed: R2.1, U1.4 (RT/CLK)
unnamed: R7.1, R8.1, U2.1 (K)
unnamed: C7.2, R5.1, R6.2, U2.2 (REF)
unnamed: C15.2, U3.4 (CAPM)
unnamed: C15.1, U3.2 (CAPP)
unnamed: C12.2, C13.2, U3.26 (LDOO)
unnamed: C16.2, U3.10 (VCOM)
unnamed: C14.1, U3.5 (VNEG)
unnamed: C29.2, R23.1, U5.4 (AIN0)
unnamed: C30.1, R24.1, U5.5 (AIN1)
unnamed: C31.1, R25.1, U5.6 (AIN2)
unnamed: C32.1, R26.1, U5.7 (AIN3)
unnamed: C33.2, U5.8 (VDD)

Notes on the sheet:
Power Management Latch
Buck Converter
AUX Sensor
REV Sensor
DAC
LDO
ILL Sensor
ADS
ADS Input
Power and Signal Input
ACC Sensor
Pi GPIO Header
UVLO
Audio Output

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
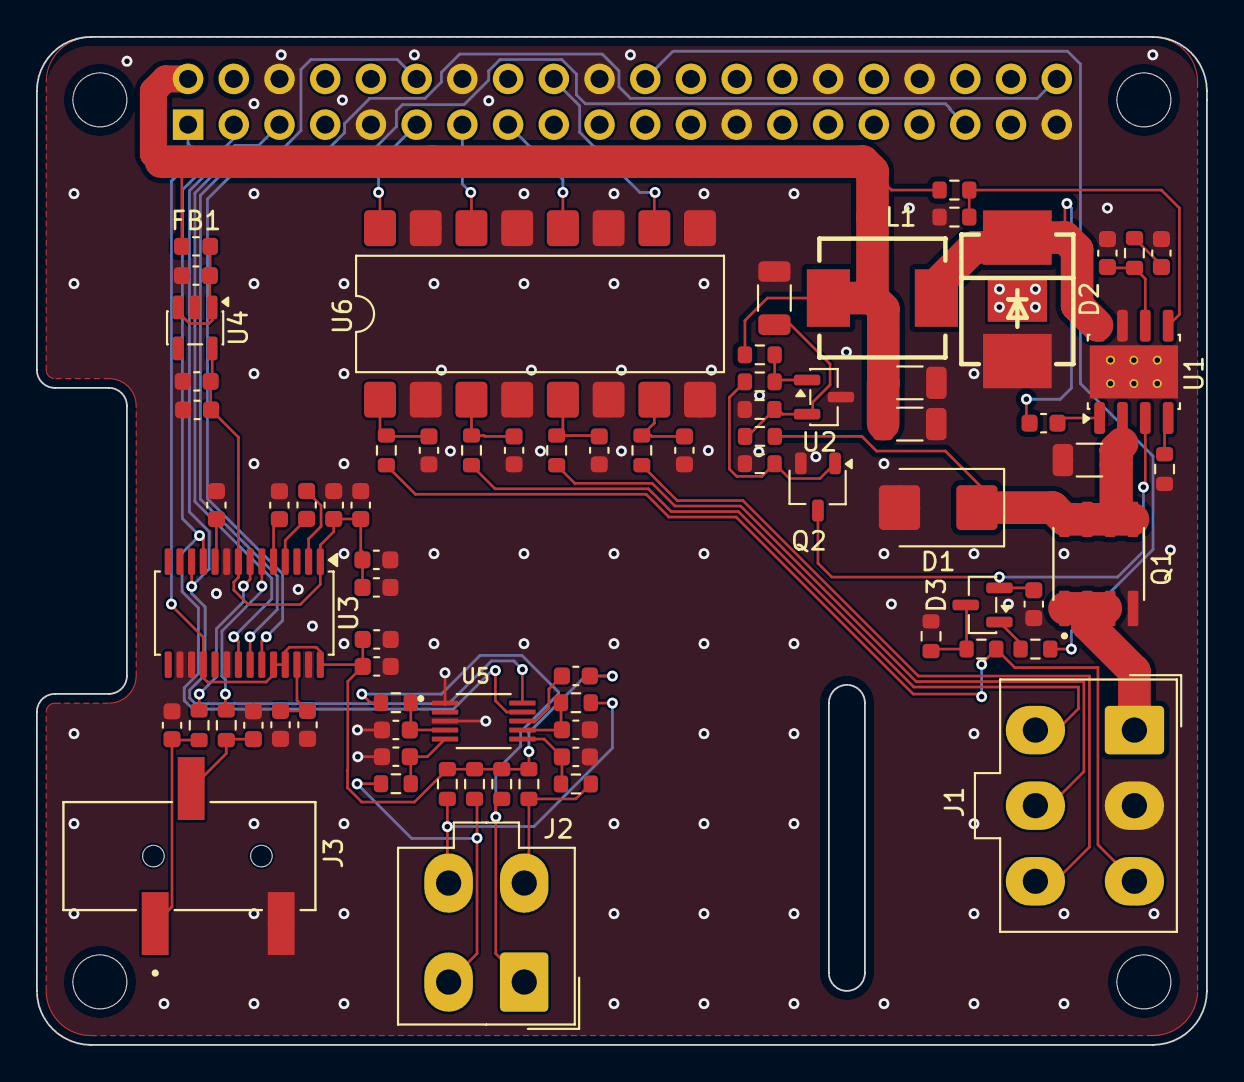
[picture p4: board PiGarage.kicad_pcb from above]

Board: 2 copper layers, 65.0 x 56.0 mm, 76 parts (1 on the bottom side), 55 nets.

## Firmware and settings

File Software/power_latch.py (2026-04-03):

#!/usr/bin/env python3
import time
import subprocess
import signal
import sys
import logging
import RPi.GPIO as GPIO

# RPiCarPowerHAT pins (BCM)
PIN_ACC   = 17   # HIGH when ACC present
PIN_LATCH = 25   # HIGH keeps power latched

# Timings (seconds)
ACC_CONFIRM_LOW = 3.0    # ACC must be low continuously for this long
SHUTDOWN_DELAY  = 2.0    # extra grace time after confirmed low
CHECK_INTERVAL  = 0.05   # polling interval (50ms)

# Logging
LOG_LEVEL = logging.INFO

def setup_logging():
    logging.basicConfig(
        level=LOG_LEVEL,
        format="%(asctime)s %(levelname)s %(message)s",
    )

def shutdown_now():
    # If your systemd service runs as root, no sudo needed.
    subprocess.run(["/sbin/shutdown", "-h", "now"], check=False)

def cleanup(signum=None, frame=None):
    try:
        logging.info("Exiting (signal=%s). Cleaning up GPIO.", signum)
    except Exception:
        pass
    GPIO.cleanup()
    sys.exit(0)

def main():
    setup_logging()

    GPIO.setmode(GPIO.BCM)

    # Prevent floating input causing false triggers
    GPIO.setup(PIN_ACC, GPIO.IN, pull_up_down=GPIO.PUD_DOWN)

    # Keep power latched on
    GPIO.setup(PIN_LATCH, GPIO.OUT, initial=GPIO.HIGH)
    logging.info("Latched power: GPIO%d=HIGH (ACC input on GPIO%d).", PIN_LATCH, PIN_ACC)

    signal.signal(signal.SIGTERM, cleanup)
    signal.signal(signal.SIGINT, cleanup)

    acc_low_since = None
    shutdown_sent = False
    last_report_bucket = None  # throttles "LOW for Xs" logs

    while True:
        acc = GPIO.input(PIN_ACC)          # 1 = ACC present, 0 = ACC absent
        now = time.monotonic()

        if acc == 0:
            if acc_low_since is None:
                acc_low_since = now
                last_report_bucket = None
                logging.info("ACC LOW detected (timer start).")
            else:
                low_for = now - acc_low_since

                # Log every ~2 seconds while low
                bucket = int(low_for // 2)
                if bucket != last_report_bucket:
                    last_report_bucket = bucket
                    logging.info("ACC LOW for %.1fs", low_for)

                if (low_for >= ACC_CONFIRM_LOW) and (not shutdown_sent):
                    shutdown_sent = True
                    logging.warning(
                        "ACC LOW confirmed (>= %.1fs). Shutdown in %.1fs.",
                        ACC_CONFIRM_LOW, SHUTDOWN_DELAY
                    )
                    time.sleep(SHUTDOWN_DELAY)
                    logging.warning("Issuing shutdown now.")
                    shutdown_now()

        else:
            if acc_low_since is not None:
                logging.info("ACC HIGH restored (timer reset).")
            acc_low_since = None
            shutdown_sent = False
            last_report_bucket = None

        time.sleep(CHECK_INTERVAL)

if __name__ == "__main__":
    main()

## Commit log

2026-03-20 Initial commit — PiGarage v0.1
    Automotive 12V→5V power management and audio HAT for Raspberry Pi 3/4/5.
    KiCad 9 hardware design, production files, BOM, and power latch daemon.
    [BOM.xlsx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]
2026-03-31 v0.2
    - Buck converter redesigned with TI WEBENCH (7-16V in, 5V/5A, 1.1MHz fsw)
    - New inductor: FXL0630-2R2-M (2.2µH, 10A Isat, 15mΩ DCR)
    - New catch diode: B560C-13-F (SMC package for better thermals)
    - Added AO4407A P-FET reverse polarity protection
    - Replaced 4× LTV-817S with 1× LTV-847S quad optocoupler
    - Switched ADS1115 back to VSSOP (IDGSR) from QFN
    - All passives upgraded from 0402 to 0603 for hand-solder friendliness
    - Fixed DAC pin connections (BCM21 for DIN, XSMT to 3.3VA)
    - Fixed ADC pull-up topology for correct voltage divider operation
    - Merged AGND into GND (shared ground per PCM5122 datasheet)
    - Added GND via stitching (65 vias)
    - Updated all 3D model paths for KiCad 10
    -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
    [BOM.xlsx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]
2026-04-03 Add thermal pad to D2 and remap GPIO sense pins
    - Added exposed copper thermal pad (GND, pad 3) with 4 thermal vias to
    D2 (B560C catch diode) footprint for improved heat dissipation at 5A
    - Remapped optoisolator GPIO assignments for cleaner PCB trace routing:
    BCM17 = ACC, BCM22 = REV, BCM27 = ILL, BCM24 = AUX
    - Updated power_latch.py PIN_ACC 27 → 17 to match new assignment
    - Updated design-notes and GPIO allocation table
    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
    [PiGarage.kicad_pcb, PiGarage.kicad_sch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]
2026-04-17 Fix D1 footprint: D_SMC (DO-214AB) → D_SMB (DO-214AA)
    SMBJ18CA ships in SMB (DO-214AA) package; the SMC footprint had
    ~60% larger pads and courtyard, causing JLCPCB preview mismatch.
    Updated pad positions (±3.4 → ±2.15 mm), pad size (3.3×2.5 →
    2.5×2.3 mm), courtyard, silkscreen, fab outline, and 3D model to
    match KiCad Diode_SMD:D_SMB. Re-routing of D1 connections required
    in KiCad after this change.
    [PiGarage.kicad_pcb, PiGarage.kicad_sch]
2026-04-17 Re-route D1 traces and refresh Gerbers after SMB footprint fix
    Updated D1 pad connections after pad positions shifted from ±3.4 mm
    to ±2.15 mm. Regenerated all Gerbers and drill files.
    [PiGarage-B_Paste.gbr, PiGarage-Board Layer Stack Bottom Overlay.gbr, PiGarage-Board Layer Stack Bottom Solder.gbr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]
2026-04-17 Update front board image
2026-04-24 Update BOM and design notes: swap 0402 passives to 0603
    All affected resistors and decoupling caps updated to 0603 footprint
    equivalents to support hand soldering. LCSC part numbers, MPNs, and
    specs updated throughout design-notes.txt. Schematic symbol properties
    updated with new 0603 LCSC numbers. BOM tracking CSV added.
    [PiGarage.kicad_sch, PiGarage_bom.csv]

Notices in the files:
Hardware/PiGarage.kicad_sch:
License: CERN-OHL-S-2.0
